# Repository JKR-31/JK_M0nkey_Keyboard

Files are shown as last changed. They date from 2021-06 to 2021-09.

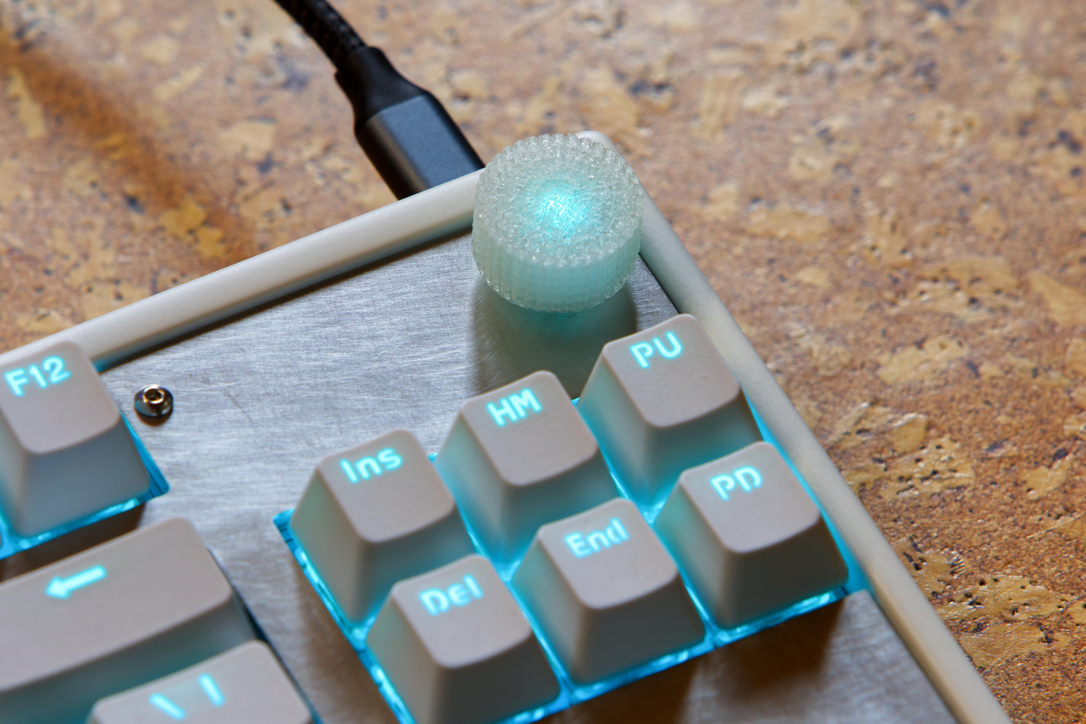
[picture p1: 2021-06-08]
Pictures/Encoder.jpg

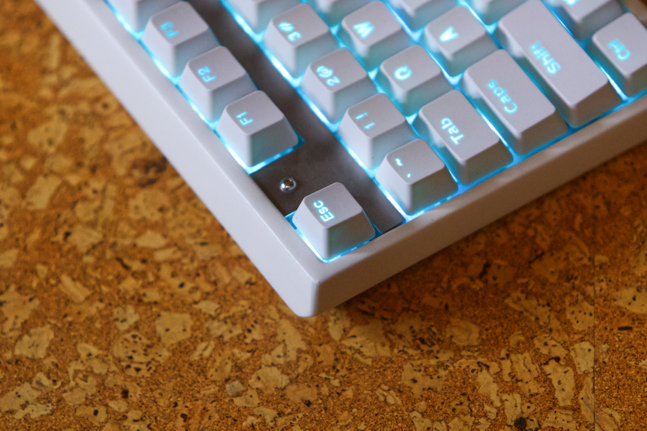
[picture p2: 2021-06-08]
Pictures/Escapeview.jpg

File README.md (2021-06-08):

# JK_M0nkey_Keyboard
Tenkeyless Keyboard with 2 Port USB-Hub

So I wanted to build myself a mechanical keyboard after seeing tones of build-videos online. But since I know how to design electrical circuits and make them in to an PCB, I decided to create it fully from scratch.
I planned the PCB in KICad and build the Housing with Freecad. The Software on the keyboard is a costume QMK firmware that i programmed.
As extra added features I wanted a USB-Hub for my mouse dongle and to connect a USB-Stick on occasion. Also an encoder for volume-adjustment and RGB backlightning was added.

The USB-Hub a Microchip USB2513BI chip was used. It is a 3 Port USB2.0 Hub controller.
The keyboard controller is standard Microchip AT90USB646.

For the housing i used Freecad to design a housing that i could print on my 3D-printer and a plate that i got lasercut out of stainless steel by a spanish company.
After printing the housing I did an lot of sanding, filling, more sanding, primer and than a white spraypaint layer and matt clearcoat.

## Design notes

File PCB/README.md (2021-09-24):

Here are all the files needed to make the PCB of my Keyboard. In the newest version with all bugfixes added.
(Fixed issues 24.09.21: missing trace at encoder, pull-up instead off pull-down at USB chip, wrong holewidth for 6,25 stab)

Also there is the .zip file that I used for upload at my PCB manufacturer of choise: JLCPCB and a picture of the options I choose on there website.
I like JLC-PCB because you can get good quality PCBs for cheap (5x for ~30EUR).

For soldering i did everything by hand. For the USB- & ATMEL-Controller and the USB-C Connector i used a hot-air-gun with solderpaste. So that i have a good connection of the groundpads.
Everything else was soldered using a soldering iron with a small tip.
It's a lot of work and it took me 3 evenings to complete.
After you finish check for any brigged connections, in particular at the USB-C port (i had that problem and nothing worked)

Also soldering and testing in steps makes sense here. So first do the USB-Hub --> test it. Than do the microcontroller --> test it.

The USB-Hub-Controller should work after everything is soldered on. It doesn't need any programming. It should show up automatically on your PC.
This controller has to work, so that we can access the USB-Bootloader of the AT90USB646.

When the USB-HUB is recognised by your PC, look in the device manager if you see the USB-Bootloader show up.
Now you just need to upload the keyboard code as described on the QMK website for any other mechanical keyboard.

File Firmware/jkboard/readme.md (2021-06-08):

# jkboard

jkboard

A tenkeyless keyboard with RGB-backlightning, an encoder and a 2 port USB2.0 Hub for your mouse and other small devices.

* Keyboard Maintainer: [Jonas Kraus](https://github.com/JK-31)
* Hardware Supported: AT90USB646 powered
* Hardware Availability: Not availible currently

Make example for this keyboard (after setting up your build environment):

    make jkboard:default

Flashing example for this keyboard:

    make jkboard:default:flash

See the [build environment setup](https://docs.qmk.fm/#/getting_started_build_tools) and the [make instructions](https://docs.qmk.fm/#/getting_started_make_guide) for more information. Brand new to QMK? Start with our [Complete Newbs Guide](https://docs.qmk.fm/#/newbs).

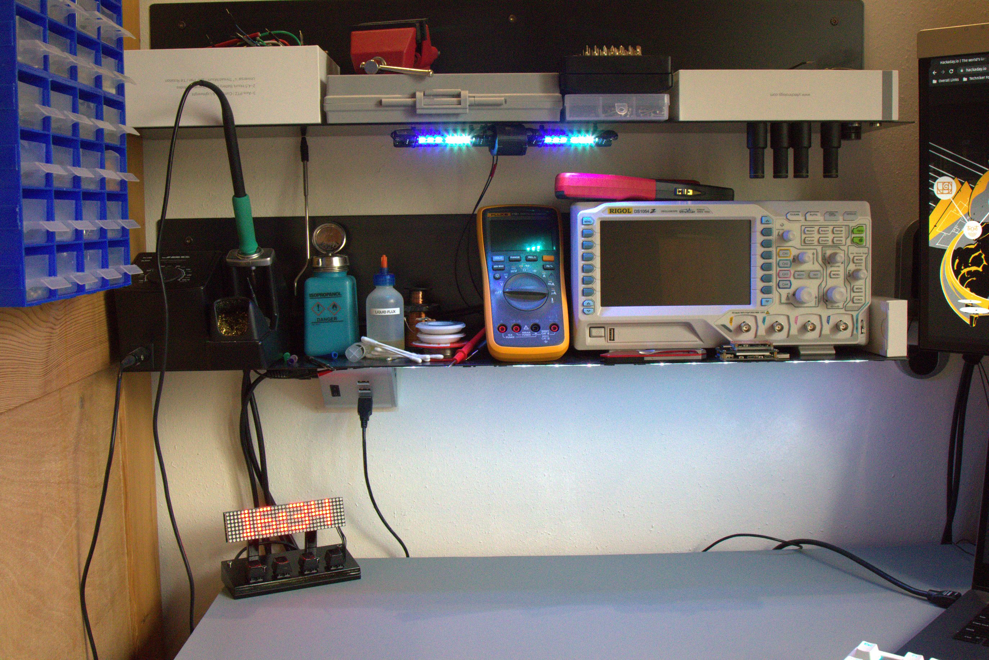
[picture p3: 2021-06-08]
Pictures/JOK_5876.jpg

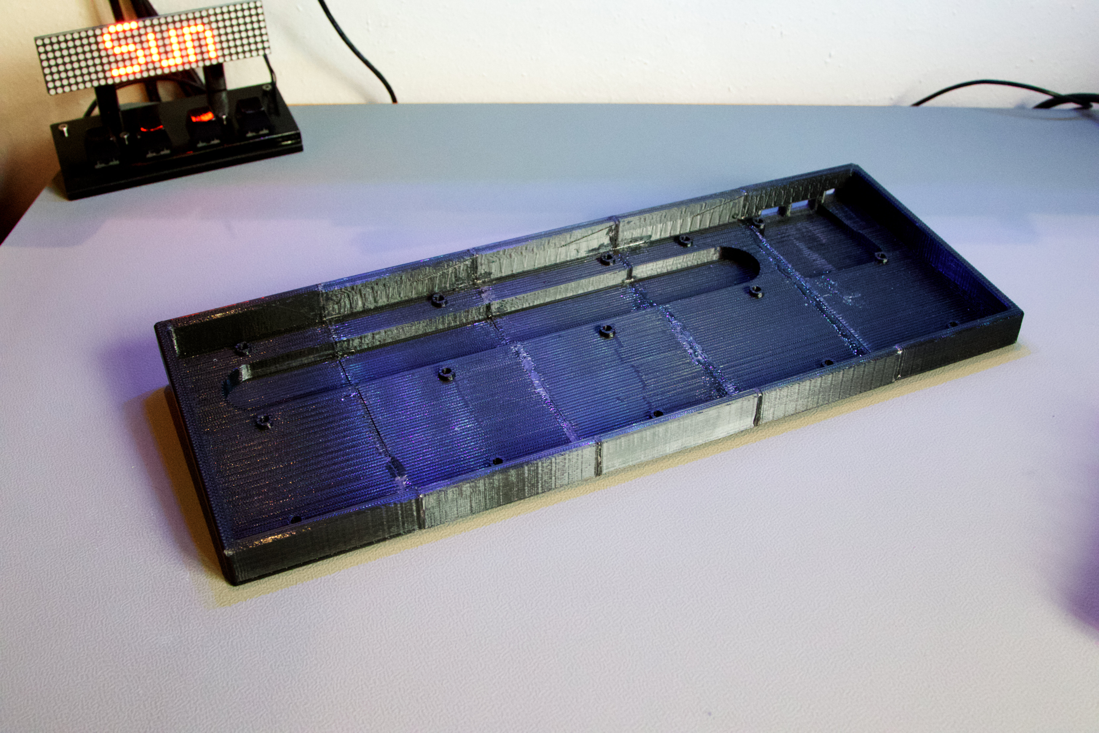
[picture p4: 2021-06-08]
Pictures/Housing_1.jpg

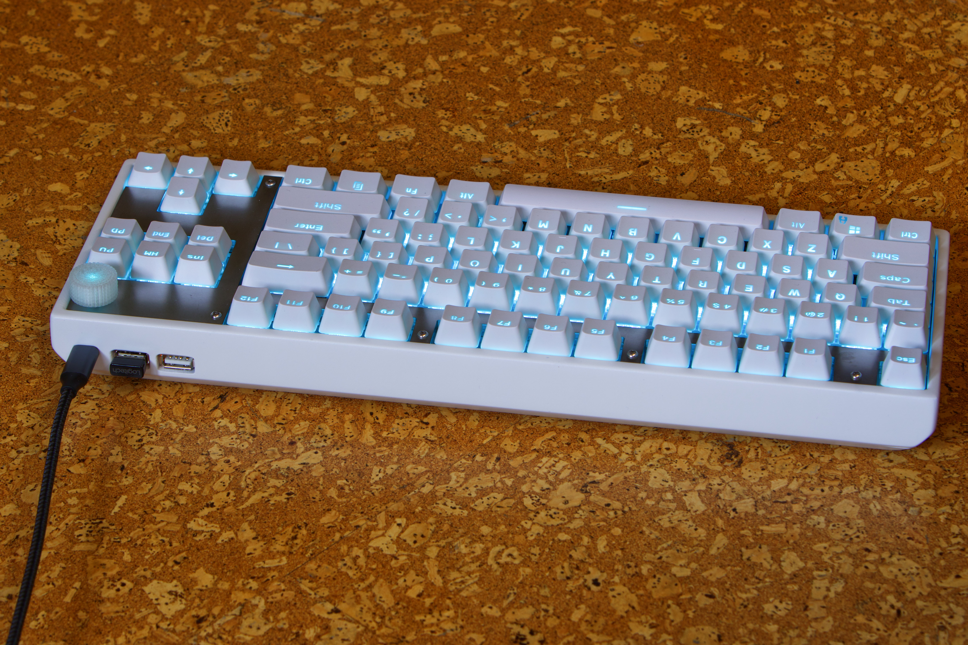
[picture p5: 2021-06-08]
Pictures/Backside.jpg

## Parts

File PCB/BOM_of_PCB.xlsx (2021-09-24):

ID | Designator | Quantity | Package | Value | Name
Kondensator
1 | C | 4 | 0402 | 1uF
2 | C | 103 | 0402 | 0,1uF
3 | C | 1 | 0402 | 2,2uF
4 | C | 2 | 0402 | 18pF
5 | C | 2 | 0402 | 10pF
6 | C | 2 | E61 | 100uF | EMZA6R3ADA101ME61G
Diode
7 | D | 85 | MINI-E | 12mA | YS-SK6812MINI-E
8 | D | 84 | SOD-323 | 4ns | 1N4148WS-HF
9 | D | 4 | 0402 | Green | HSMG-C280
10 | D | 3 | 0402 | Yellow | HSMG-C280
Fuse
11 | F | 1 | 1206 | 4A | SF-1206S300-2
12 | F | 6 | 0603 | 3A | Ferrit MPZ1608S221ATA00
Connectors
13 | J | 1 |  | USB-C | DX07S016JA1R1500
14 | J | 2 |  | USB-A | TE 292303-3
15 | J | 1 | 1.27mm |  | PinHeader_2x4_P1.27mm_SMD
Mechanical
16 | M |  |  |  | 2u_Stab
17 | M |  |  |  | 6.25u_Stab
Resistors
18 | R | 1 | 0402 | 12k
19 | R | 4 | 0402 | 150R
20 | R | 4 | 0402 | 10k
21 | R | 4 | 0402 | 0R
22 | R | 1 | 0402 | 500R
23 | R | 3 | 0402 | 100R
24 | R | 2 | 0402 | 22R
25 | R | 8 | 0402 | 100k
26 | R | 3 | 0402 | 330R
27 | R | 2 | 0402 | 5.1k
Switches
28 | S | 1 |  |  | Amphenol E15TS-06
29 | S | 2 |  |  | PTS526_SM15_SMTR2_LFS
30 | S | 84 |  |  | cherry mx kailh socket
Integrated Chips
31 | U | 4 |  |  | PRTR5V0U2X
32 | U | 1 |  |  | USB2513BI-AEZG
33 | U | 1 |  |  | MIC2026A-1YM-TR
34 | U | 1 |  |  | AP2112K-3.3TRG1
35 | U | 1 |  |  | AT90USB646-MU
Crystals
36 | Y | 1 |  | 16MHz | ECS-160-10-36B-CKM-TR
37 | Y | 1 |  | 24MHz | ECS-240-18-33B-7KM-TR

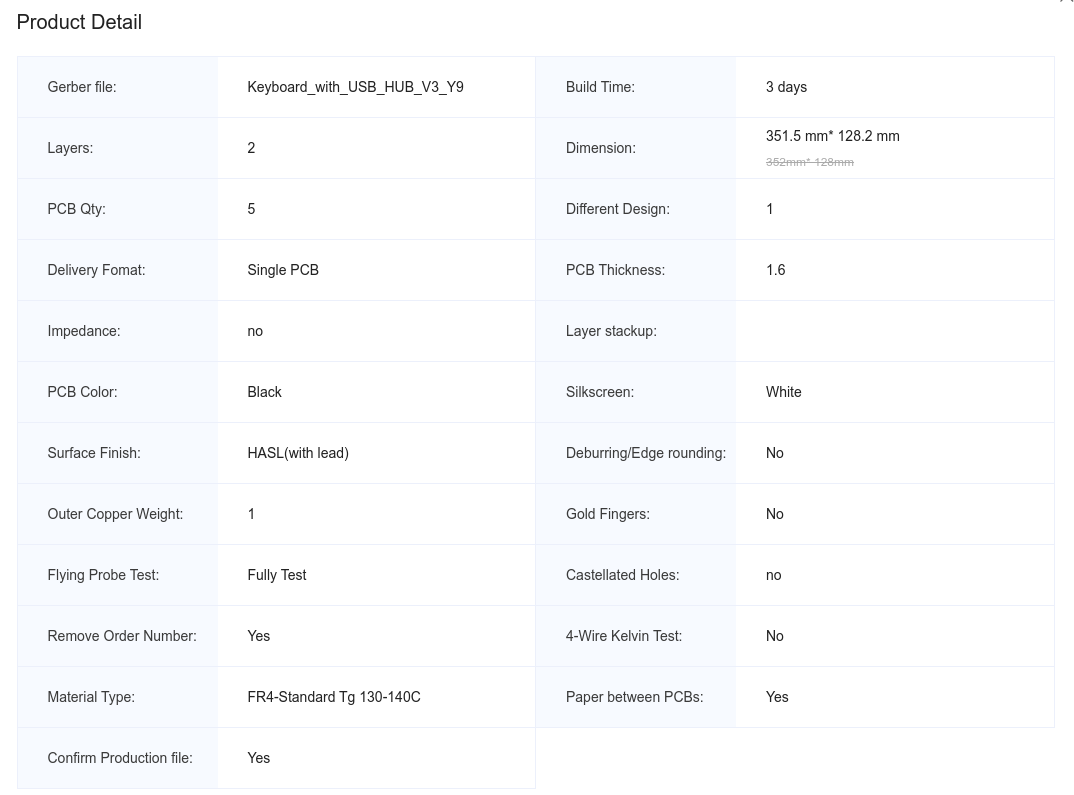
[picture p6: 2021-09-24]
PCB/JLC-PCB_order_options.png

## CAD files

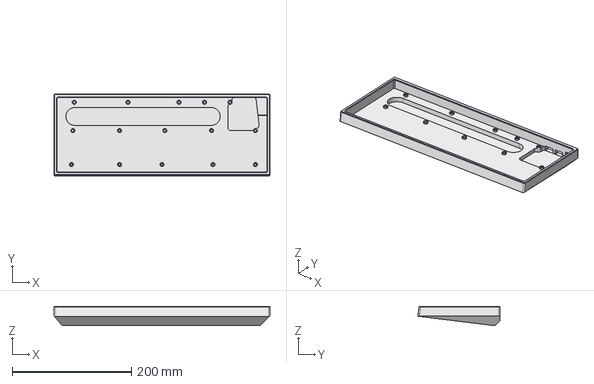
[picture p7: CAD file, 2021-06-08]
CAD/Body.step
362.5 x 138.1 x 32.6 mm

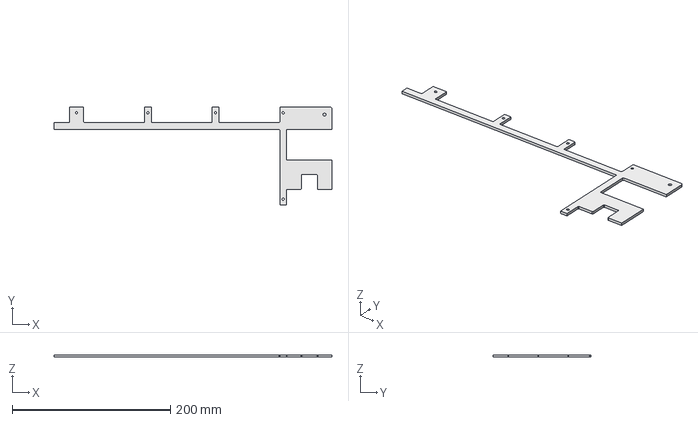
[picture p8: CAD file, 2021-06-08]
CAD/Plate3.step
351.5 x 123.5 x 3.00 mm

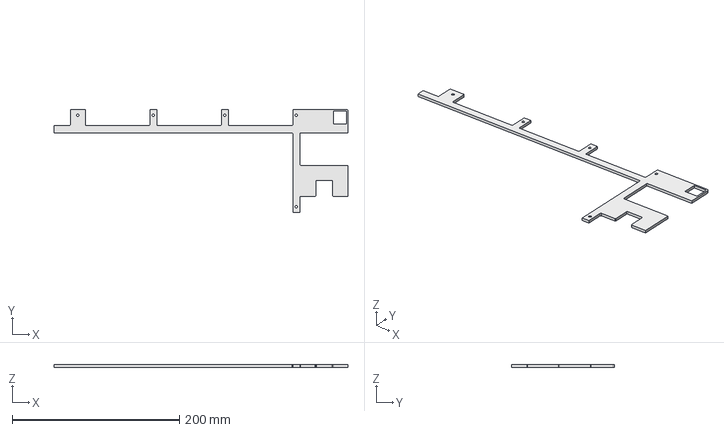
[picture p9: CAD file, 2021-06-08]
CAD/Plate2.step
351.5 x 123.5 x 3.00 mm

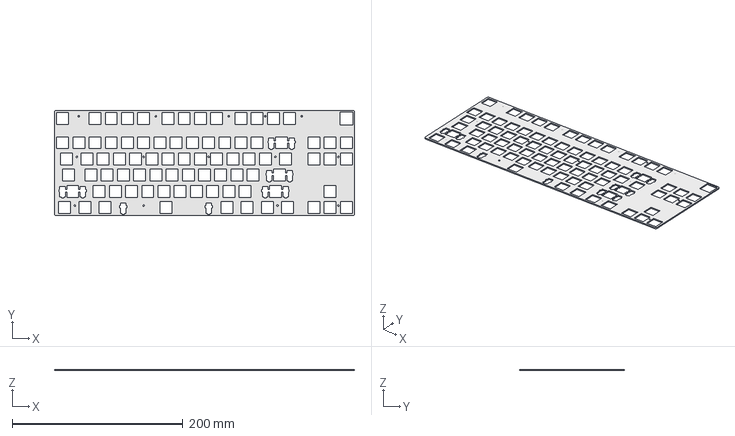
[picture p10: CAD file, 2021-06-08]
CAD/Plate1.step
351.5 x 123.5 x 1.50 mm

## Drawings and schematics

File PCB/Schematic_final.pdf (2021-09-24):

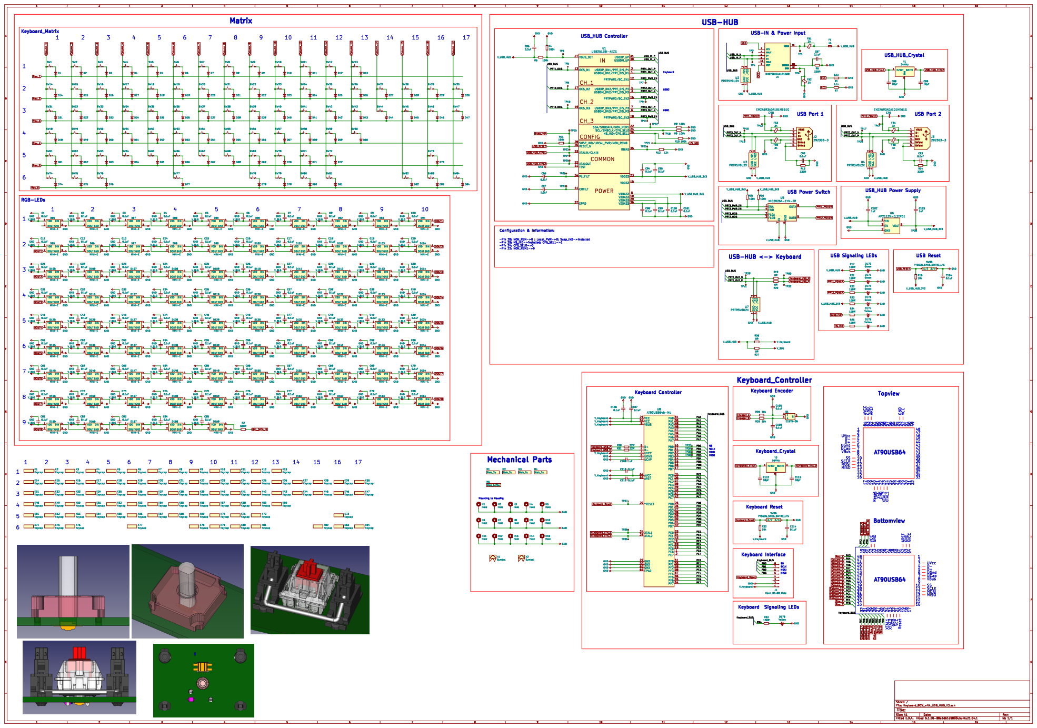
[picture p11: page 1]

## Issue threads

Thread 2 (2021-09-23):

Instructions on Ordering and Assembling PCB?

howardt12345, 2021-09-23:
Hi, I'm Howard, and I stumbled upon your project when looking for a keyboard that has the exact same specs that the keyboard you designed has. I just want to say that you did an absolutely amazing job at designing this keyboard, it's such a nice keyboard and one I would love to have myself.

I'm looking to make this keyboard for myself. However, given my lack of experience in electrical engineering, I'm really not sure on how to use the files provided in your repository, and what I additional information I should provide to a PCB prototype manufacturer in order to get a PCB created for this keyboard.  May you please update the [readme](https://github.com/JKR-31/JK_M0nkey_Keyboard/blob/main/PCB/readme.md) in the PCB folder with instructions on how to order the PCB from a PCB prototype manufacturer such as JLCPCB or PCBWay, and how to assemble the PCB? I, and many others who might seek to build the keyboard you designed, would greatly appreciate it.

Also, it would be really nice if you were to open source the KICad files for this keyboard as well. I would love to use this project as a reference for my own potential keyboard designs if you don't mind.

JKR-31, 2021-09-24:
Hi Howard,

cool that you found my project and liked it.
I updated the PCB directory. I added the same zip-file that I used to order the PCB from JLC-PCB and also a screenshot of all the options that i choose on my order.
Also wrote some things in the read-me about the assembly process.

As a tip if you ever design something similar with a USB-Hub. I mostly referenced my schematic on one of the demo-/evaluation-boards, that microchip sells. Most of the manufactures of these USB-Hub-chips offer these demoboards and also upload the schematics for those on there websites.
(here the link: https://www.microchip.com/en-us/development-tool/EVB-USB2513BC & http://ww1.microchip.com/downloads/en/DeviceDoc/evb2513q36bas.pdf)

howardt12345, 2021-09-24:
Thank you so much for the help!

Closed 2021-09-24.

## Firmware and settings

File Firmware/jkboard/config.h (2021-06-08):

/*
Copyright 2021 Jonas Kraus

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
You should have received a copy of the GNU General Public License
along with this program.  If not, see <http://www.gnu.org/licenses/>.
*/

#pragma once

#include "config_common.h"

/* USB Device descriptor parameter */
#define VENDOR_ID    0x3101
#define PRODUCT_ID   0x1999
#define DEVICE_VER   0x0003
#define MANUFACTURER Jonas Kraus
#define PRODUCT      jkboard_v3

/* key matrix size */
#define MATRIX_ROWS 6
#define MATRIX_COLS 17

/*
 * Keyboard Matrix Assignments
 *
 * Change this to how you wired your keyboard
 * COLS: AVR pins used for columns, left to right
 * ROWS: AVR pins used for rows, top to bottom
 * DIODE_DIRECTION: COL2ROW = COL = Anode (+), ROW = Cathode (-, marked on diode)
 *                  ROW2COL = ROW = Anode (+), COL = Cathode (-, marked on diode)
 *
 */
#define MATRIX_ROW_PINS { A3, E1, E0, D2, D1, D4 }
#define MATRIX_COL_PINS { A4, A5, A6, A7, E2, C7, C6, C5, C4, C3, C2, C1, C0, D3, D5, D6, D7 }
#define UNUSED_PINS { B0, B1, B2, B3, B4, B5, B6, B7, D0, E3, E4, E5, E6, E7, F0, F1, F2, F3, F4, F5, F6, F7 }

/* COL2ROW, ROW2COL */
#define DIODE_DIRECTION COL2ROW

/*
 * Split Keyboard specific options, make sure you have 'SPLIT_KEYBOARD = yes' in your rules.mk, and define SOFT_SERIAL_PIN.
 */
//#define SOFT_SERIAL_PIN D0  // or D1, D2, D3, E6

//#define LED_NUM_LOCK_PIN B0
//#define LED_CAPS_LOCK_PIN B1
//#define LED_SCROLL_LOCK_PIN B2
//#define LED_COMPOSE_PIN B3
//#define LED_KANA_PIN B4

//#define BACKLIGHT_PIN B7
//#define BACKLIGHT_LEVELS 3
//#define BACKLIGHT_BREATHING

#define RGB_DI_PIN A0
#ifdef RGB_DI_PIN
#    define RGBLED_NUM 85
#    define RGBLIGHT_HUE_STEP 8
#    define RGBLIGHT_SAT_STEP 8
#    define RGBLIGHT_VAL_STEP 8
#    define RGBLIGHT_LIMIT_VAL 255 /* The maximum brightness level */
#    define RGBLIGHT_SLEEP  /* If defined, the RGB lighting will be switched off when the host goes to sleep */
/*== all animations enable ==*/
#    define RGBLIGHT_ANIMATIONS
/*== or choose animations ==*/
//#    define RGBLIGHT_EFFECT_BREATHING
//#    define RGBLIGHT_EFFECT_RAINBOW_MOOD
//#    define RGBLIGHT_EFFECT_RAINBOW_SWIRL
//#    define RGBLIGHT_EFFECT_SNAKE
//#    define RGBLIGHT_EFFECT_KNIGHT
//#    define RGBLIGHT_EFFECT_CHRISTMAS
//#    define RGBLIGHT_EFFECT_STATIC_GRADIENT
//#    define RGBLIGHT_EFFECT_RGB_TEST
//#    define RGBLIGHT_EFFECT_ALTERNATING
/*== customize breathing effect ==*/
/*==== (DEFAULT) use fixed table instead of exp() and sin() ====*/
//#    define RGBLIGHT_BREATHE_TABLE_SIZE 256      // 256(default) or 128 or 64
/*==== use exp() and sin() ====*/
//#    define RGBLIGHT_EFFECT_BREATHE_CENTER 1.85  // 1 to 2.7
//#    define RGBLIGHT_EFFECT_BREATHE_MAX    255   // 0 to 255
#endif

/* Debounce reduces chatter (unintended double-presses) - set 0 if debouncing is not needed */
#define DEBOUNCE 5

/* define if matrix has ghost (lacks anti-ghosting diodes) */
//#define MATRIX_HAS_GHOST

/* Mechanical locking support. Use KC_LCAP, KC_LNUM or KC_LSCR instead in keymap */
#define LOCKING_SUPPORT_ENABLE
/* Locking resynchronize hack */
#define LOCKING_RESYNC_ENABLE

/* If defined, GRAVE_ESC will always act as ESC when CTRL is held.
 * This is useful for the Windows task manager shortcut (ctrl+shift+esc).
 */
//#define GRAVE_ESC_CTRL_OVERRIDE

/*
 * Force NKRO
 *
 * Force NKRO (nKey Rollover) to be enabled by default, regardless of the saved
 * state in the bootmagic EEPROM settings. (Note that NKRO must be enabled in the
 * makefile for this to work.)
 *
 * If forced on, NKRO can be disabled via magic key (default = LShift+RShift+N)
 * until the next keyboard reset.
 *
 * NKRO may prevent your keystrokes from being detected in the BIOS, but it is
 * fully operational during normal computer usage.
 *
 * For a less heavy-handed approach, enable NKRO via magic key (LShift+RShift+N)
 * or via bootmagic (hold SPACE+N while plugging in the keyboard). Once set by
 * bootmagic, NKRO mode will always be enabled until it is toggled again during a
 * power-up.
 *
 */
//#define FORCE_NKRO

/*
 * Feature disable options
 *  These options are also useful to firmware size reduction.
 */

/* disable debug print */
//#define NO_DEBUG

/* disable print */
//#define NO_PRINT

/* disable action features */
//#define NO_ACTION_LAYER
//#define NO_ACTION_TAPPING
//#define NO_ACTION_ONESHOT

/* disable these deprecated features by default */
#define NO_ACTION_MACRO
#define NO_ACTION_FUNCTION

/* Bootmagic Lite key configuration */
//#define BOOTMAGIC_LITE_ROW 0
//#define BOOTMAGIC_LITE_COLUMN 0

/* Encoder port configurator */
#define ENCODERS_PAD_A { A2 }
#define ENCODERS_PAD_B { A1 }
#define ENCODER_DIRECTION_FLIP
#define ENCODER_RESOLUTION 4

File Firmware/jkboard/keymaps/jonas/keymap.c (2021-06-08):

/* Copyright 2021 Jonas Kraus
 *
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
 * You should have received a copy of the GNU General Public License
 * along with this program.  If not, see <http://www.gnu.org/licenses/>.
 */
#include QMK_KEYBOARD_H

// Defines names for use in layer keycodes and the keymap
enum layer_names {
    _BASE,
    _FN
};

const uint16_t PROGMEM keymaps[][MATRIX_ROWS][MATRIX_COLS] = {
    /* Base */
    [_BASE] = LAYOUT(
        KC_ESC,	KC_F1,    KC_F2,    KC_F3,    KC_F4,    KC_F5,    KC_F6,    KC_F7,    KC_F8,    KC_F9,    KC_F10,   KC_F11,   KC_F12, \
        KC_GRV,   KC_1,     KC_2,     KC_3,     KC_4,     KC_5,     KC_6,     KC_7,     KC_8,     KC_9,     KC_0,     KC_MINS,  KC_EQL,   KC_BSPC,  KC_INS,   KC_HOME,  KC_PGUP, \
        KC_TAB,   KC_Q,     KC_W,     KC_E,     KC_R,     KC_T,     KC_Y,     KC_U,     KC_I,     KC_O,     KC_P,     KC_LBRC,  KC_RBRC,  KC_BSLS,  KC_DEL,   KC_END,   KC_PGDOWN, \
        KC_CAPS,  KC_A,     KC_S,     KC_D,     KC_F,     KC_G,     KC_H,     KC_J,     KC_K,     KC_L,     KC_SCLN,  KC_QUOT,  KC_ENT, \
        KC_LSFT,  KC_Z,     KC_X,     KC_C,     KC_V,     KC_B,     KC_N,     KC_M,     KC_COMM,  KC_DOT,   KC_SLSH,  KC_RSHIFT,                              KC_UP, \
        KC_LCTL,  KC_LGUI,  KC_LALT,                      KC_SPC,                       KC_RALT,  MO(_FN),  KC_APP,   KC_RCTL,                     KC_LEFT,  KC_DOWN,  KC_RIGHT
        ),
        
    [_FN] = LAYOUT(
        KC_TRNS,  KC_TRNS,  KC_TRNS,  KC_TRNS,  KC_TRNS,  KC_TRNS,  KC_TRNS,  KC_TRNS,  KC_TRNS,  RGB_TOG,  RGB_MOD,  RGB_RMOD, RGB_M_P, \
        RESET,    KC_TRNS,  KC_TRNS,  KC_TRNS,  KC_TRNS,  KC_TRNS,  KC_TRNS,  KC_TRNS,  KC_TRNS,  KC_TRNS,  KC_TRNS,  KC_TRNS,  KC_TRNS,  KC_TRNS,  RGB_HUI,  RGB_SAI,  RGB_VAI, \
        KC_TRNS,  KC_TRNS,  KC_TRNS,  KC_TRNS,  KC_TRNS,  KC_TRNS,  KC_TRNS,  KC_TRNS,  KC_TRNS,  KC_TRNS,  KC_TRNS,  KC_TRNS,  KC_TRNS,  KC_TRNS,  RGB_HUD,  RGB_SAD,  RGB_VAD, \
        KC_TRNS,  KC_TRNS,  KC_TRNS,  KC_TRNS,  KC_TRNS,  KC_TRNS,  KC_TRNS,  KC_TRNS,  KC_TRNS,  KC_TRNS,  KC_TRNS,  KC_TRNS,  KC_TRNS, \
        KC_TRNS,  KC_TRNS,  KC_TRNS,  KC_TRNS,  KC_TRNS,  KC_TRNS,  KC_TRNS,  KC_TRNS,  KC_TRNS,  KC_TRNS,  KC_TRNS,  KC_TRNS,                                KC_TRNS, \
        EEP_RST,  KC_TRNS,  KC_TRNS,                      KC_TRNS,                      KC_TRNS,  KC_TRNS,  KC_TRNS,  KC_TRNS,                      KC_TRNS,  KC_TRNS,  KC_TRNS
        ),
};

/* The encoder_update_user is a function.
 * It'll be called by QMK every time you turn the encoder.
 *
 * The index parameter tells you which encoder was turned. If you only have
 * one encoder, the index will always be zero.
 * 
 * The clockwise parameter tells you the direction of the encoder. It'll be
 * true when you turned the encoder clockwise, and false otherwise.
 */
void encoder_update_user(uint8_t index, bool clockwise) {
  /* With an if statement we can check which encoder was turned. */
  if (index == 0) { /* First encoder */
    /* And with another if statement we can check the direction. */
    if (clockwise) {
      /* This is where the actual magic happens: this bit of code taps on the
         Page Down key. You can do anything QMK allows you to do here.
         You'll want to replace these lines with the things you want your
         encoders to do. */
      tap_code(KC_VOLU);
    } else {
      /* And likewise for the other direction, this time Page Down is pressed. */
      tap_code(KC_VOLD);
    }
}
}

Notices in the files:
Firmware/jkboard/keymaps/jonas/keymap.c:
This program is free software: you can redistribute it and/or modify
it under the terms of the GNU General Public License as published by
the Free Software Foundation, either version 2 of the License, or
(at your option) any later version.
